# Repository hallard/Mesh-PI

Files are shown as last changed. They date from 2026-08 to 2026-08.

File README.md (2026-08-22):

# Mesh-PI — The tiniest LoRa board for Raspberry Pi



<p align="center">
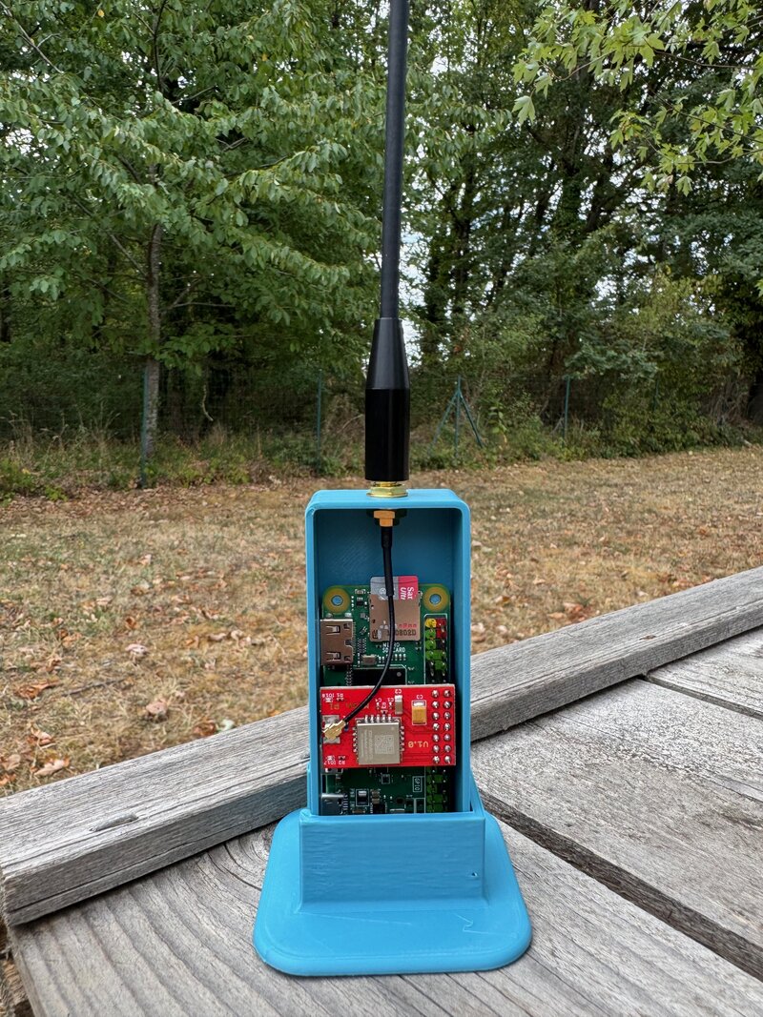
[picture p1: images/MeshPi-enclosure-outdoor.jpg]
Mesh-PI node in a 3D-printed enclosure with antenna, deployed outdoors
  
</p>

**Mesh-PI** is, as far as I know, the **smallest SX1262 LoRa board ever made for the Raspberry Pi**. It's built around the ultra-small **10×10 mm** [Ebyte **E22-900MM22S**][e22] (Semtech **SX1262**, 868/915 MHz) module — the board is barely bigger than the module itself.

It's designed to run [Meshtastic][meshtastic] with the Linux-native daemon [`meshtasticd`][meshtasticd], but since it's just a plain SX1262 on the SPI bus, it works with **any LoRa / LoRa-mesh stack** — Meshtastic, [Reticulum / RNode][reticulum], your own [RadioLib][radiolib] project… Ideal for a compact, always-on **router / MQTT gateway** node, with the full power of Linux behind it: SSH, MQTT, Home Assistant, scripting…

## Features

**Version 1.0**

- Placement for **Ebyte E22-900MM22S** module — SX1262, 868/915 MHz ISM, up to **22 dBm**, ~7 km range, 10×10 mm
- **u.FL** antenna connector — or solder an edge-mount **SMA** connector / wire antenna instead
- **2 status LEDs** (Green = OK, Red = fault) driven from GPIO
- Powered straight from the Pi **3.3 V** rail, with proper bulk + low-ESR decoupling (100 µF tantalum + 47 µF MLCC + 100 nF)
- Designed for **`meshtasticd`** (Meshtastic Linux-native)

## Design choices

Mesh-PI is deliberately **minimal and purpose-built for a static router node** — small, cheap, efficient, and it does exactly that job, perfectly.

- **No GPS — on purpose.** Dropped to save space and cost. A fixed router doesn't move, so its location is set once as a *fixed position* in Meshtastic; an on-board GPS would only add size, price and power draw for nothing.
- **22 dBm — on purpose.** The board uses the SX1262's native **22 dBm** rather than a 1 W (30 dBm) amplified front-end. Going 1 W would mean tapping the Pi **5 V** rail and adding a dedicated 3.3 V regulator for the extra current — which would blow up the whole "tiny shield" idea. At 22 dBm the module runs **straight off the Pi 3.3 V** and stays cool. The E22-900 covers **850–930 MHz**, so it works in **EU868**, **US915** and the other 900 MHz regions. ⚠️ Meshtastic does **not** auto-cap the output to the EU legal limit — you must set the TX power yourself (see the **Power limits & regulations** section below).

Small, focused, and it just works. 🎯

## Schematics

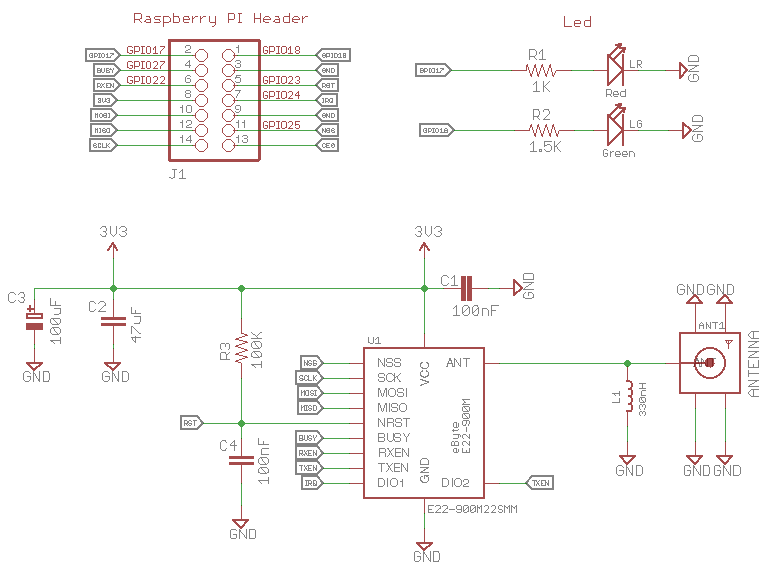
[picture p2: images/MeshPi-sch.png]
Schematics


SPI is the classic MOSI / MISO / SCLK. **NSS (chip-select) sits on GPIO25** — a free GPIO, *not* CE0 — to avoid the `cs-gpios` conflict of recent Raspberry Pi kernels (meshtasticd / RadioLib drives it directly). The RF switch uses **DIO2 for TX** (`DIO2_AS_RF_SWITCH`) and a GPIO for RX.

```
Raspberry PI            E22-900MM22S (SX1262)
   GPIO25  <---->  NSS   (chip select)
   SCLK    <---->  SCK
   MOSI    <---->  MOSI
   MISO    <---->  MISO
   GPIO23  <---->  NRST  (reset, active low)
   GPIO27  <---->  BUSY
   GPIO24  <---->  DIO1  (IRQ)
   GPIO22  <---->  RXEN
   DIO2    <---->  TXEN  (tied together -> DIO2_AS_RF_SWITCH)
   DIO3    :  not connected  (32 MHz XTAL on module, no TCXO)

Raspberry PI         On Board LEDs
   GPIO18  <---->  Green LED (status OK)
   GPIO17  <---->  Red LED   (fault)
```

## Assembled boards

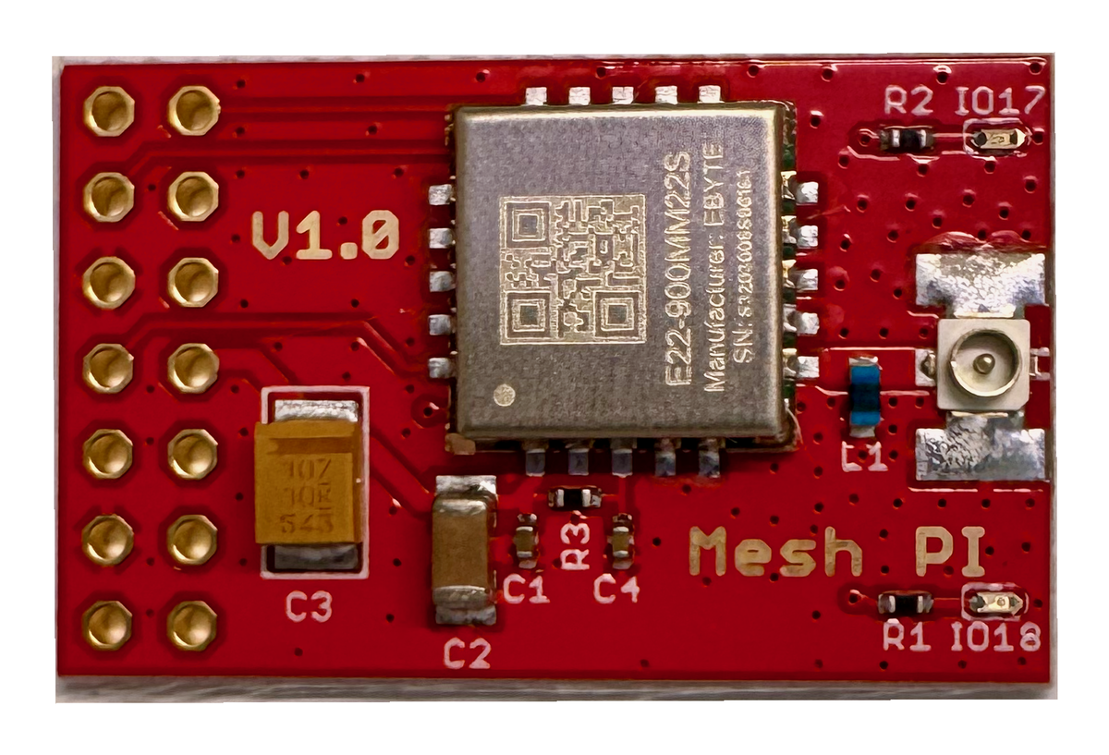
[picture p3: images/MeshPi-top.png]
Top


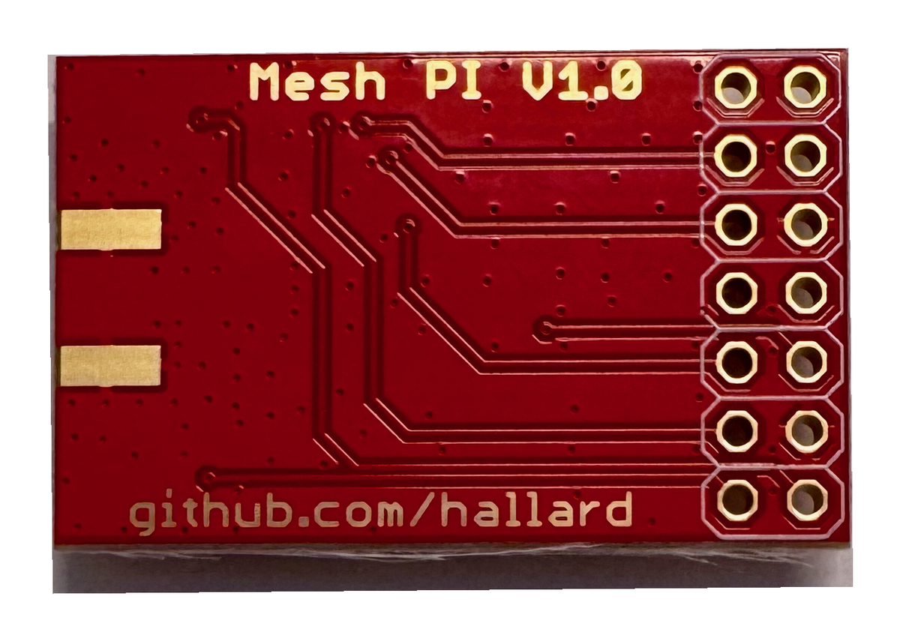
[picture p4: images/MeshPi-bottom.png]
Bottom


## Mounting

Mesh-PI is a **partial HAT** — its 2×7 socket plugs onto a **14-pin block of the Pi's 40-pin GPIO header: physical pins 11 → 24**. Position it *exactly* as shown, and it can only go one way:

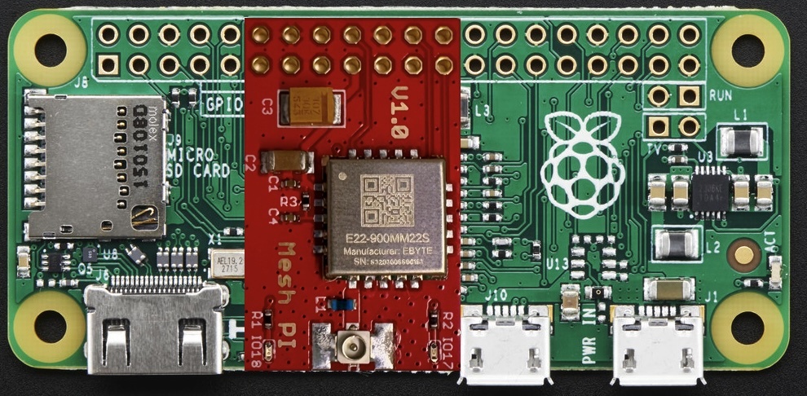
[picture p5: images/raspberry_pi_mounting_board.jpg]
Mesh-PI position on the Raspberry Pi GPIO header (physical pins 11–24)


- The socket covers **pins 11–24** — pins **1–10 stay free** on the SD-card side, **25–40 free** on the other side.
- Mount it **exactly as in the photo above** — don't shift it by a row or plug it in flipped: any offset puts the radio on the wrong pins.
- Press it **fully and squarely** onto the header *before* powering the Pi.

## 3D printed case

Need an enclosure? **Finn** designed a neat [Meshtastic Raspberry Pi Zero 2 W case with foot](https://www.printables.com/model/1252555-meshtastic-raspberry-pi-zero-2-w-case-with-foot) on Printables — a simple, stationary enclosure with an integrated stand, purpose-built for a headless Pi Zero 2 W LoRa node (no buttons, GPS or display to cut out). A great way to finish off a Mesh-PI router.

Big thanks to **Finn** for designing and sharing it! 🙏

## Software — meshtasticd

Install the Meshtastic Linux daemon (see the [official docs][meshtasticd]), then declare the radio in `/etc/meshtasticd/config.yaml`:

```yaml
Lora:
  Module: sx1262
  CS: 25
  IRQ: 24
  Busy: 27
  Reset: 23
  RXen: 22
  DIO2_AS_RF_SWITCH: true
  # No DIO3_TCXO_VOLTAGE — the E22-900MM22S uses a passive 32 MHz XTAL, not a TCXO
```

> ⚠️ **Do NOT** set `DIO3_TCXO_VOLTAGE` on this board. The **MM22S** variant is crystal-based; setting it would tell the SX1262 to power a non-existent TCXO and the radio would fail to init (`-707`). *(The larger M22S is TCXO — that's a different module.)*

Enable SPI and set the boot state of the reset / LED pins in `/boot/firmware/config.txt`:

```
dtparam=spi=on

# Keep the radio out of reset from the bootloader (NRST is active-low -> drive high)
gpio=23=op,dh
# LEDs off at boot (active-high -> drive low)
gpio=17,18=op,dl
```

Then set the LoRa region and node role from any Meshtastic client (the phone app), or the [Meshtastic Python CLI](https://meshtastic.org/docs/software/python/cli/installation/) — install it with `pipx install meshtastic`, then:

```
meshtastic --host localhost --set lora.region EU_868 --set device.role ROUTER
```

## ⚠️ Power limits & regulations

The E22-900MM22S can transmit at up to **22 dBm (~160 mW)**, and Meshtastic's `EU_868` preset will happily let it — on a Mesh-PI I measured `Final Tx power: 22 dBm`, **not** capped to any lower value.

**In the EU, the 868 MHz ISM band is legally limited** — over most of the band that's **25 mW ERP (~14 dBm)**. Running the radio at 22 dBm where that isn't permitted is a **regulatory violation**, and it is entirely up to you to comply with your own country's rules.

So on this board, **set the TX power yourself** — don't leave it at the region maximum. It's the `lora.tx_power` setting, in dBm:

```
meshtastic --host localhost --set lora.tx_power 14
```

(or in the phone app: **LoRa → Tx Power**). A value of `0` means *"use the region maximum"*, so set an explicit value — e.g. **14** for the EU — to stay within your legal limit.

> **Disclaimer:** you alone are responsible for operating this board within your local radio regulations. The author is **not responsible** for any misuse, non-compliant configuration, or interference caused by running it above the legal power limit for your region.

## Status LEDs

The two on-board LEDs give an at-a-glance health status, blinked from GPIO by a small `systemd` service:

- 🟢 **Green (GPIO18)** blinks when WiFi *and* `meshtasticd` are both up
- 🔴 **Red (GPIO17)** blinks when either one is down

The script is [`scripts/monitoring-led.sh`](scripts/monitoring-led.sh) (uses `gpioset` from libgpiod v2).

### Install

```bash
# 1. Copy the script in place
sudo install -m 0755 scripts/monitoring-led.sh /usr/local/bin/monitoring-led.sh

# 2. Create the systemd service
sudo tee /etc/systemd/system/monitoring-led.service > /dev/null <<'EOF'
[Unit]
Description=Mesh-PI monitoring LEDs (green=OK, red=fault)
After=NetworkManager.service meshtasticd.service

[Service]
Type=simple
ExecStart=/usr/local/bin/monitoring-led.sh
Restart=always
RestartSec=5

[Install]
WantedBy=multi-user.target
EOF

# 3. Enable + start (runs at every boot)
sudo systemctl enable --now monitoring-led
```

Check with `systemctl status monitoring-led` — the green LED should start blinking. The `gpio=17,18=op,dl` line in `config.txt` above keeps both LEDs off during boot, before the service takes over.

## License

This design is licensed under a [Creative Commons Attribution-NonCommercial-ShareAlike 4.0 International License][cc-by-nc-sa] — build it, tweak it, share it, but **not for commercial use**.

[][cc-by-nc-sa]

## Lazy building your own?

If I put a batch of these on [Lectronz][lectronz], you'll be able to order one there.

[][lectronz]

## Misc

News and other projects on my [blog][blog].

[meshtastic]: https://meshtastic.org
[meshtasticd]: https://meshtastic.org/docs/software/linux/installation/
[reticulum]: https://reticulum.network/
[radiolib]: https://github.com/jgromes/RadioLib
[e22]: https://www.cdebyte.com/products/E22-900MM22S
[lectronz]: https://lectronz.com/stores/hallard
[cc-by-nc-sa]: https://creativecommons.org/licenses/by-nc-sa/4.0/
[cc-badge]: https://licensebuttons.net/l/by-nc-sa/4.0/88x31.png
[blog]: https://hallard.me

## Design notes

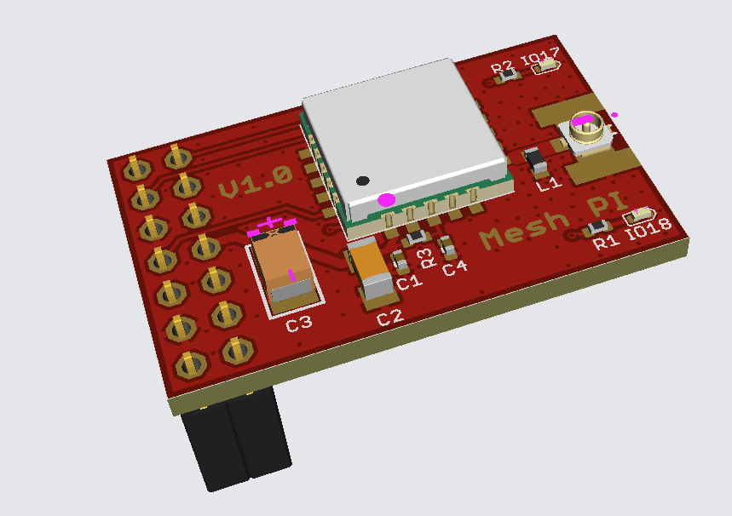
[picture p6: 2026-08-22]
images/MeshPi-3D.png

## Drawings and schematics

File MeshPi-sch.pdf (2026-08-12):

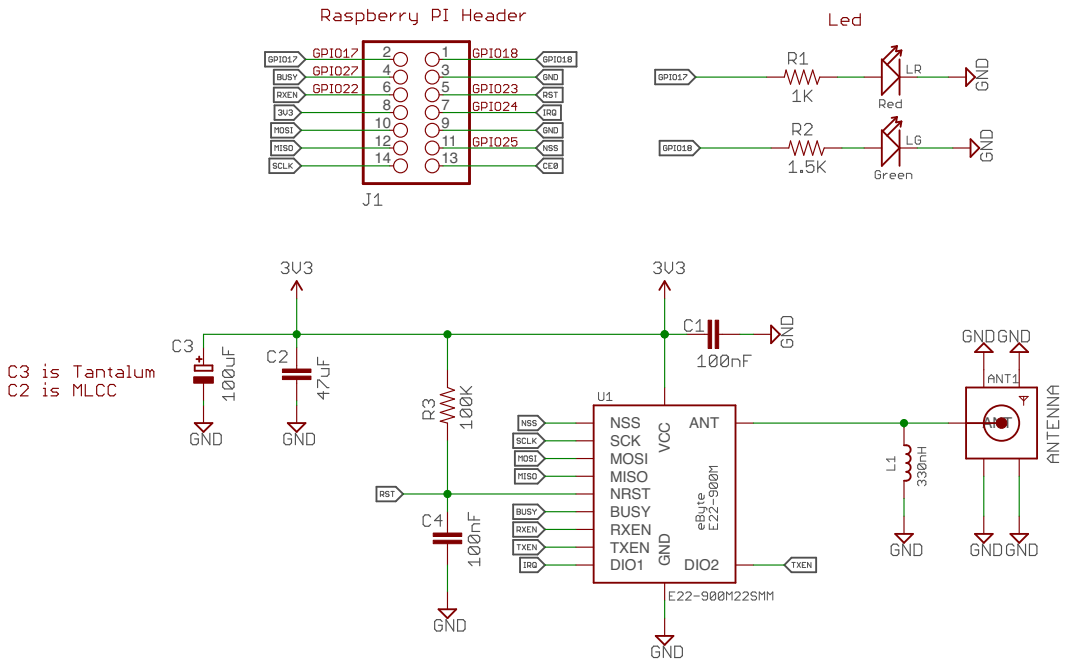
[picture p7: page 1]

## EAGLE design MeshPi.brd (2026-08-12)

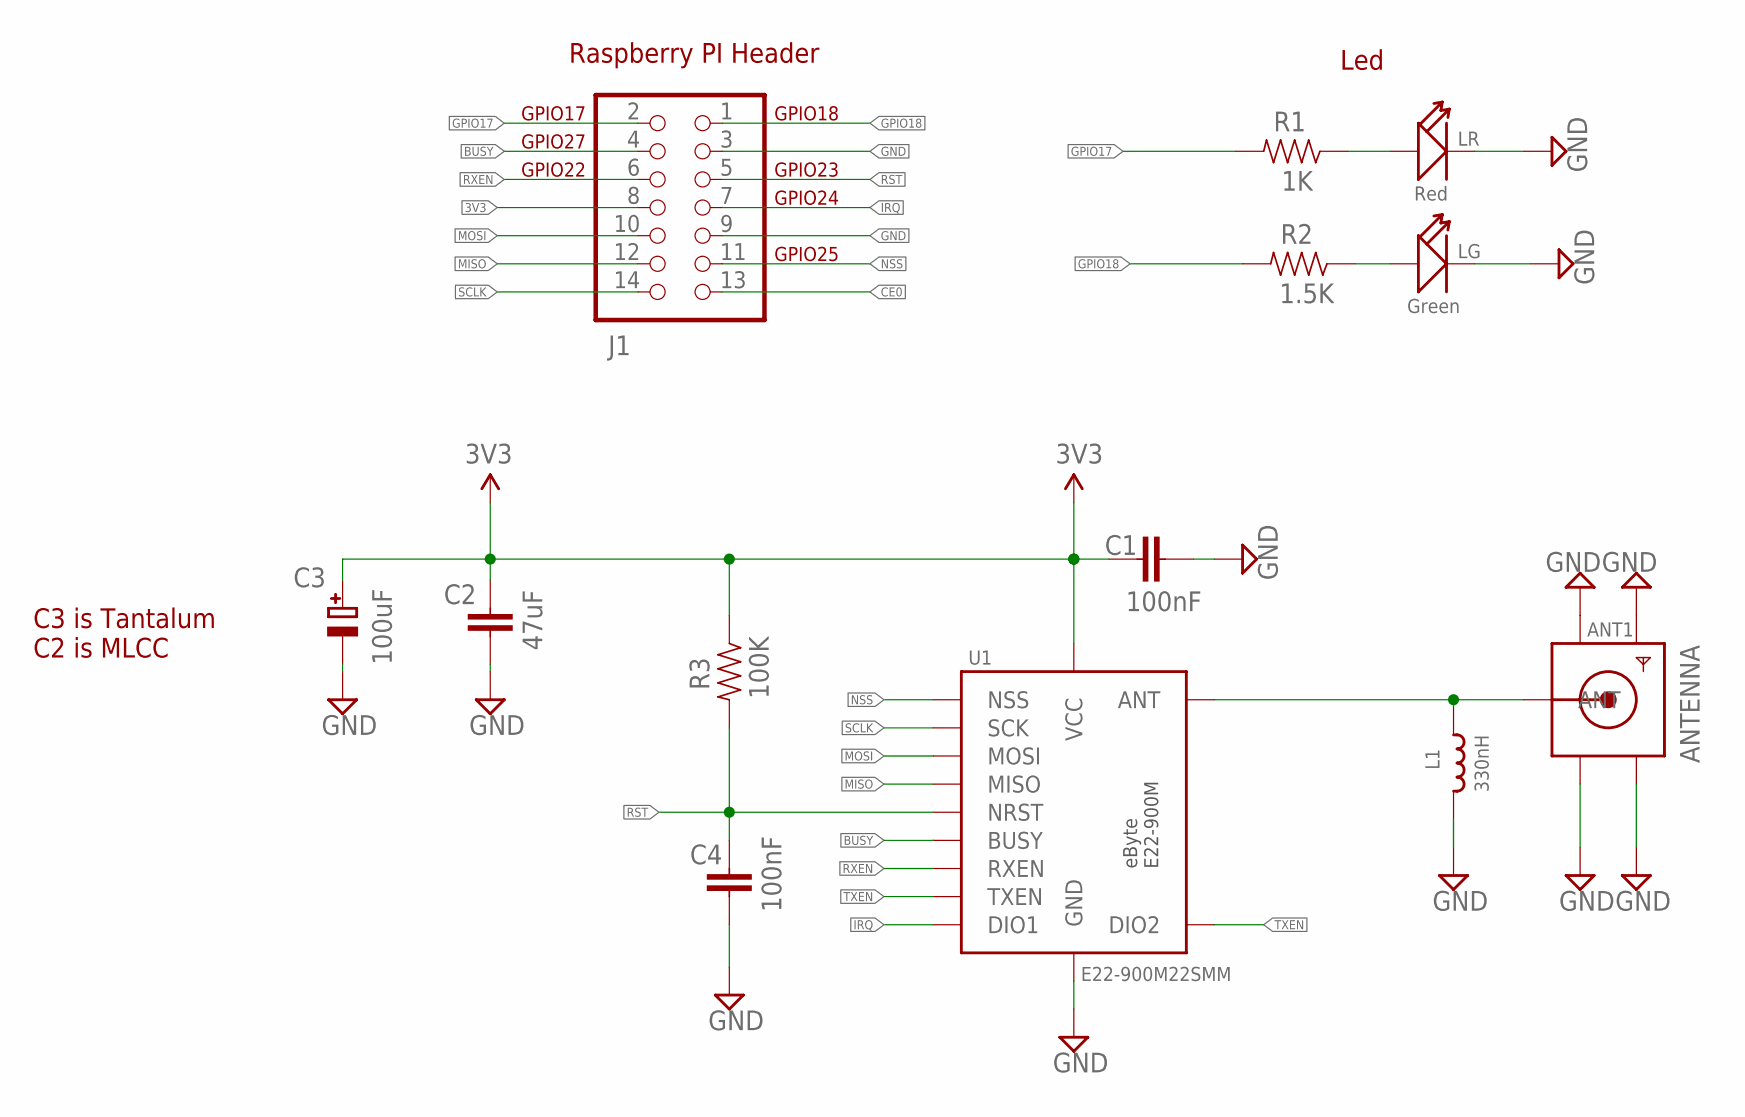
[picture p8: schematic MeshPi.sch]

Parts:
ANT1: SMACONNECTOR_EDGE_UFL; SMA_EDGELAUNCH_UFL
C1, C4: 100nF; 0402-CAP
C2: 47uF; 1206
C3: 100uF; EIA3528-21/B-R
J1: PINHD-2X7; 2X07
L1: 330nH; _0603MP
LG: Green; LED-0402
LR: Red; LED-0402
R1: 1K; 0402-RES
R2: 1.5K; 0402-RES
R3: 100K; 0402-RES
U1: E22-900M22SMM; E22-900MM2S

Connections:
3V3: C1.2, C2.2, C3.+, J1.8, R3.1, U1.P$1 (VCC)
ANTENNA: ANT1.P (ANT), L1.1, U1.P$6 (ANT)
BUSY: J1.4, U1.P$11 (BUSY)
CE0: J1.13
GND: ANT1.GND@1 (GND1), ANT1.GND@2 (GND2), ANT1.GND@3 (GND3), ANT1.GND@4 (GND4), C1.1, C2.1, C3.-, C4.1, J1.3, J1.9, L1.2, LG.-, LR.-, U1.P$2 (GND), U1.P$7 (GND), U1.P$16 (GND)
GPIO17: J1.2, R1.2
GPIO18: J1.1, R2.2
IRQ: J1.7, U1.P$20 (DIO1)
MISO: J1.12, U1.P$12 (MISO)
MOSI: J1.10, U1.P$13 (MOSI)
unnamed: LR.+, R1.1
unnamed: LG.+, R2.1
NSS: J1.11, U1.P$14 (NSS)
RST: C4.2, J1.5, R3.2, U1.P$3 (NRST)
RXEN: J1.6, U1.P$10 (RXEN)
SCLK: J1.14, U1.P$15 (SCK)
TXEN: U1.P$9 (TXEN), U1.P$19 (DIO2)

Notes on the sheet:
C3 is Tantalum C2 is MLCC
Raspberry PI Header
Led
GPIO18
GPIO23
GPIO24
GPIO25
GPIO17
GPIO27
GPIO22

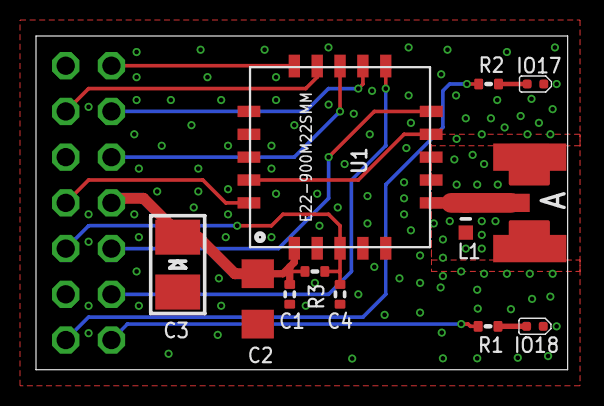
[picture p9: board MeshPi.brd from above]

Board: 2 copper layers, 29.5 x 18.5 mm, 13 parts (1 on the bottom side), 16 nets.

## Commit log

2026-08-12 Initial commit — Mesh-PI V1.0
    Tiniest SX1262 (Ebyte E22-900MM22S) LoRa board for Raspberry Pi,
    designed for Meshtastic / meshtasticd. Includes Eagle source (.sch/.brd),
    gerbers, 3D/top/bottom renders and README.
    [MeshPi.GBL, MeshPi.GBO, MeshPi.GBP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]
2026-08-12 Add monitoring-led status service and install procedure
2026-08-21 Fix SX1262 pinout (NSS25/BUSY27/RXEN22) + real board photos
2026-08-21 README: add link to Finn's 3D printed case
2026-08-21 README: add Mounting section (board position on GPIO header)
2026-08-21 Makes schematics easier to read
    Makes schematics easier to read, zoomed on only util part
2026-08-22 README: add EU power-limit warning + how to set lora.tx_power
2026-08-22 README: use outdoor enclosure photo as the header image

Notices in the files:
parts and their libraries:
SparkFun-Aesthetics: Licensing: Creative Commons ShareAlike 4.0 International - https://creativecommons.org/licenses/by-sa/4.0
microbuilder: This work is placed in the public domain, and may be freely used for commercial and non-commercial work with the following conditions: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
